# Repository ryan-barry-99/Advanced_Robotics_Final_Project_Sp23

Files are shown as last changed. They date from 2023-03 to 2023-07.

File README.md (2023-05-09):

# Balloon Trajectory Matching Omnidirectional Robot using YOLOv8

This project is designed to track a balloon using a custom YOLO model and a 3-wheeled omnidirectional drive robot, which can move in any direction without having to turn. The goal is to punch the balloon back into the air using the robot.

# Dataset and Model

The YOLOv8 model was trained on the V2 Balloon Detection dataset (https://www.kaggle.com/datasets/vbookshelf/v2-balloon-detection-dataset), resulting in efficient real-time detections at high accuracies. The model was trained using PyTorch, and the best weights were saved to the included yolov8_weights.pt file.

# Hardware Compatibility

For compatibility with DepthAI and OpenCV AI Kit hardware, the model must be saved in the Luxonis MyriadX Blob format. To achieve this, the weights were converted to the OpenVINO format using http://tools.luxonis.com/, and then the OpenVINO files were converted to the blob format using http://blobconverter.luxonis.com/.

# Code

The code for the ROS architecture that supports this robot is located in the Deployment folder. Files contained inside are as follows:
- QuadEncoder.py: Defines a class for extracting position and velocity data from quadrature encoders
- balloon_velocity.py: Deploys custom YOLOv8 model for detection and tracking, and publishes the velocity of a detected balloon
- forward_kinematics.py: Defines a class to compute the forward kinematics of an N-wheeled omnidirectional robot
- inverse_kinematics.py: Defines a class to compute the inverse kinematics of an N-wheeled omnidirectional robot
- motor.py: Defines a class for controlling a DC motor via software PWM signal
- pid_controller.py: Defines a PIDController class for use in updating wheel velocities
- pinout.py: Defines a dictionary containing the pinout for the robot. Updating pins here reflects the change globally
- robot_constants.py: Defines a dictionary containing the constants of an individual mobile robot. Updating the constants here reflects the change globally
- servo.py: Defines a class that enables PWM control for a servo
- update_target_velocity.py: Updates and publishes the robot's target velocity based on its current velocity and the balloon's velocity
- wheel_velocity_controller.py: Uses the PIDController class to match the robot's targeted and actual velocity

# Dependencies

For training YOLO:
- pandas
- numpy
- os
- ast
- sklearn
- shutil
- tqdm
- matplotlib
- torch
- IPython
- ultralytics
- clearml
- PyYAML

For Deployment:
- depthai
- time
- Jetson.GPIO
- math
- pathlib
- sys
- opencv-python
- numpy
- rospy

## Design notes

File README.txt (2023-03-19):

Balloon Puncher using YOLOv5 and Omnidirectional Robot

This project aims to track a balloon using YOLOv5 and punch it back into the air using a 3 wheeled omnidirectional drive robot. The robot moves in any direction without having to turn, which makes it perfect for this task.

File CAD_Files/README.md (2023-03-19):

# CAD Files for Tri-wheel Holonomic Robot
This repository contains the CAD (computer-aided design) files for a three wheeled omnidirectional drive robot. The CAD files are provided in SLDPRT and SLDASM and can be used for SOLIDWORKS 2021.

## Contents:
- 33_tooth_Gear.SLDPRT: 33 Tooth Gear to be 3D printed and screwed to side of wheel
- 3in_shaft.SLDPRT: Placeholder axle for chassis assembly. A carriage bolt was used on the physical prototype
- Bearing, Sealed, 608-2RS, 22X8X7.step.SLDPRT: 608-2RS bearing. 2 per wheel and 2 per wheel mount
- Din_Rail_8in.STEP: 8 inch aluminum din rail. Feel free to use another material of your choice but the brackets were designed for din rail
- Omni_Drive_Base.SLDASM: Full chassis assembly
- Omni_Roller.SLDPRT: 3D printable roller for Swedish wheel
- Omni_wheel_side.SLDPRT: Side panel of Swedish 90 wheel. Built in roller pins and press fit holes for bearings
- Omni_Wheel_Assembly.SLDASM: Full assembly of 3D printable Swedish 90 wheel
- Wheel_Mount.SLDPRT: 3D printable 120 deg bracket for wheel shafts. Press fit bearing holes
- clip.SLDPRT: Screw in clips to hold foam board on chassis
- spacer_025.SLDPRT: Allows wheel to freely rotate without interference from bolt head
- washer.SLDPRT: To be placed between wheel halfs and give rollers room for free rotation

## File Formats
The CAD files were created using SOLIDWORKS 2021 and are compatible with the 2021 version or later. If you need the files in a different format, you can use the software's export function to convert them.

## Usage
To open the CAD files, open SOLIDWORKS and select File > Open. Navigate to the location of the CAD files and select the one you want to open. You can then view and edit the part as needed.

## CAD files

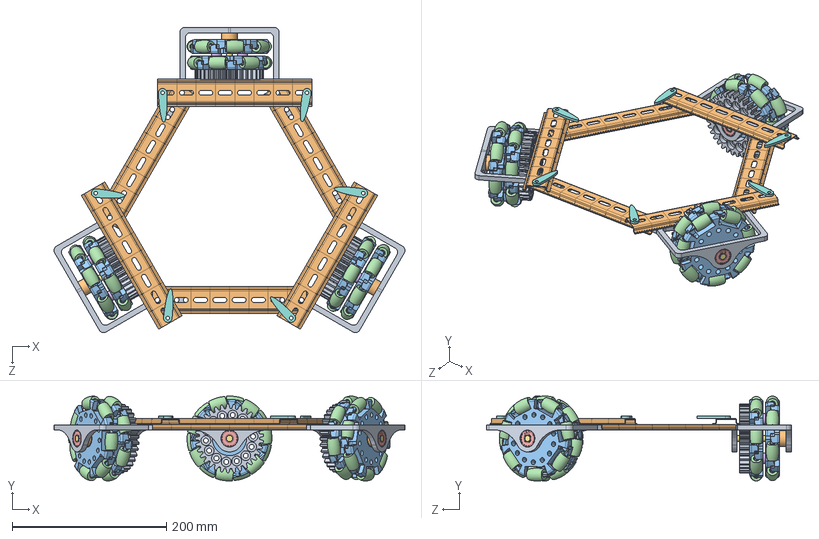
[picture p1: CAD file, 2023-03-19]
CAD_Files/Omni_Drive_Base.SLDASM
454.4 x 110.0 x 395.2 mm
Wheel_Mount x 3
din rail.STEP x 48
Omni_wheel_side x 12
Omni_Roller x 42
Bearing, Sealed, 608-2RS, 22X8X7.step x 12
washer x 6
3in_shaft x 3
clip x 6
33_tooth_Gear x 3
spacer_025 x 3

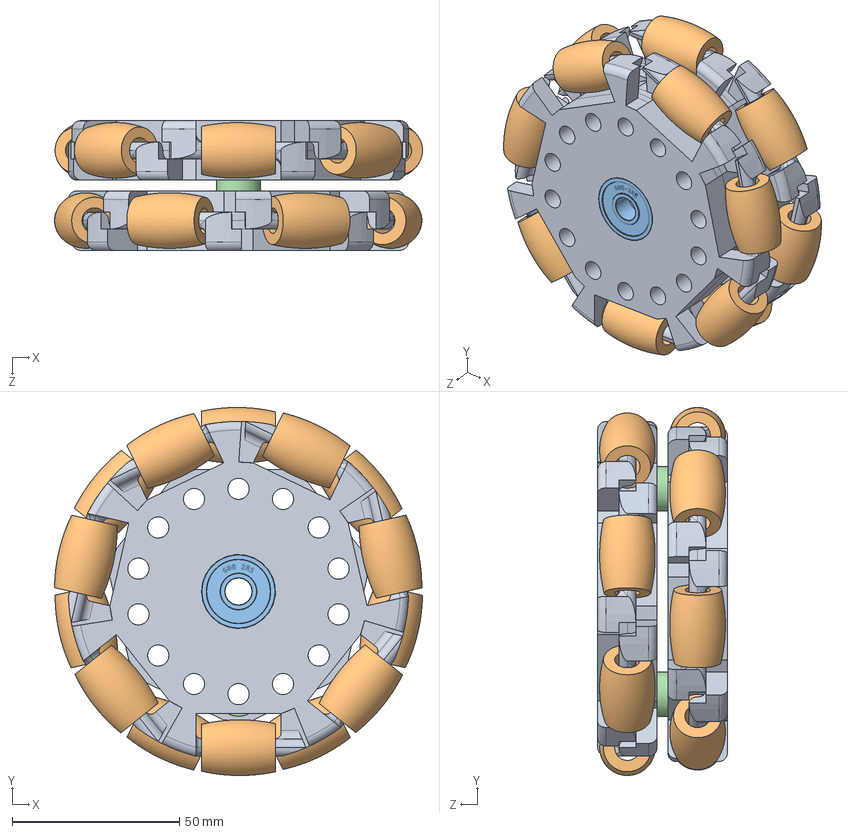
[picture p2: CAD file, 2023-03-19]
CAD_Files/Omni_Wheel_Assembly.SLDASM
109.9 x 109.9 x 38.7 mm
Omni_wheel_side x 4
Omni_Roller x 14
Bearing, Sealed, 608-2RS, 22X8X7.step x 2
washer x 2

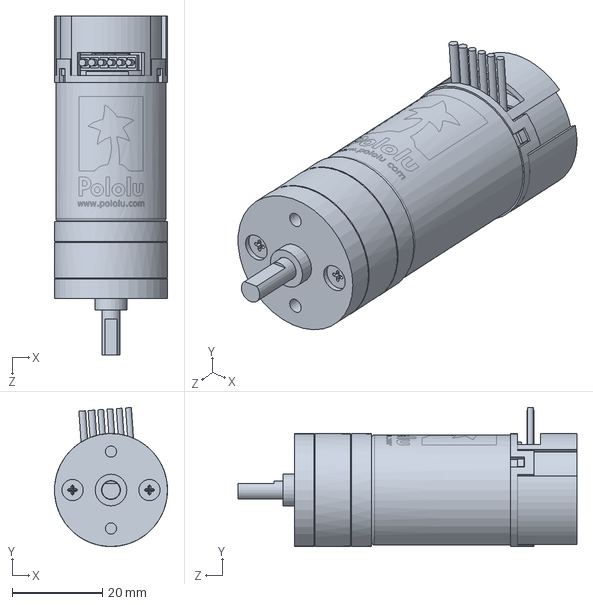
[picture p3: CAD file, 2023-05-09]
CAD_Files/25d-metal-gearmotor-4.4-9.7-encoder.SLDPRT
25.0 x 30.7 x 74.9 mm

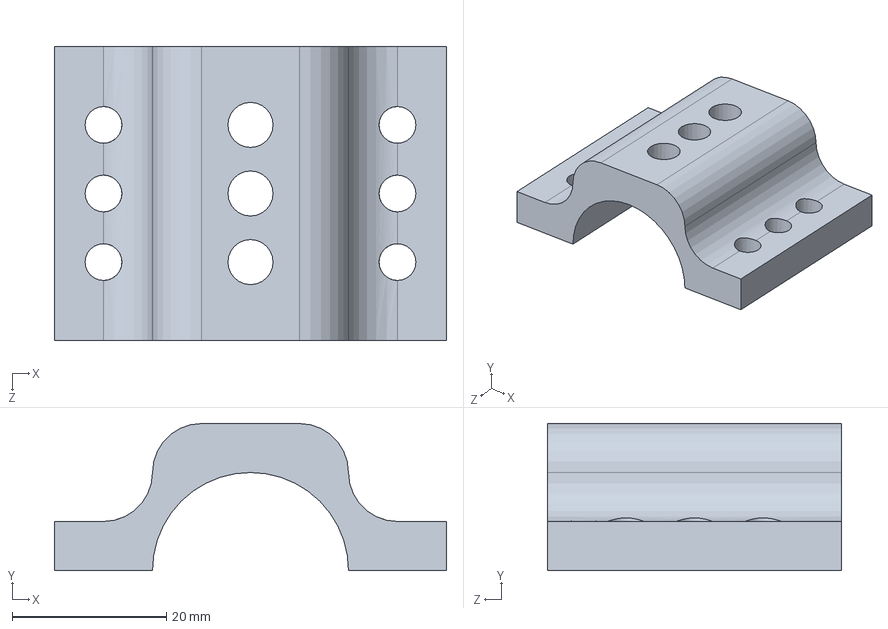
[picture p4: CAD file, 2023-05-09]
CAD_Files/Motor_Mount_Top.SLDPRT
50.8 x 19.1 x 38.1 mm

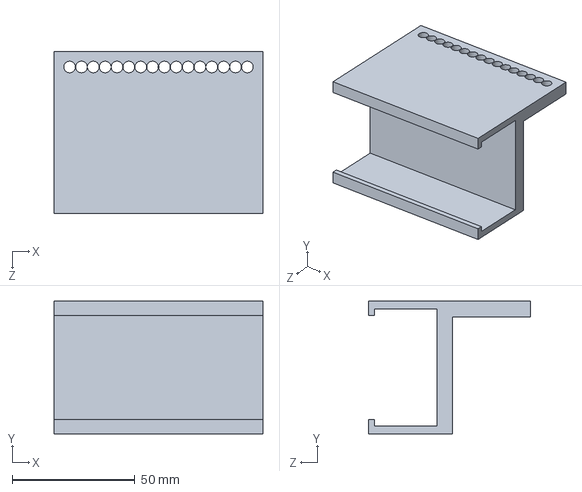
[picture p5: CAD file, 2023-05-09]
CAD_Files/Battery Holder.SLDPRT
85.1 x 54.0 x 66.0 mm

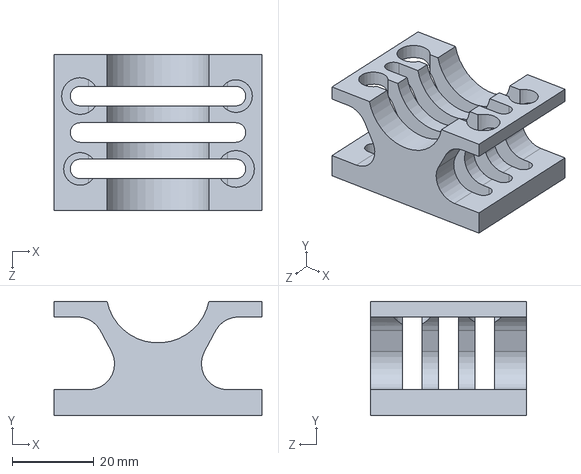
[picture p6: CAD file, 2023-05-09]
CAD_Files/Motor_Mount_Bottom.SLDPRT
50.8 x 27.9 x 38.1 mm

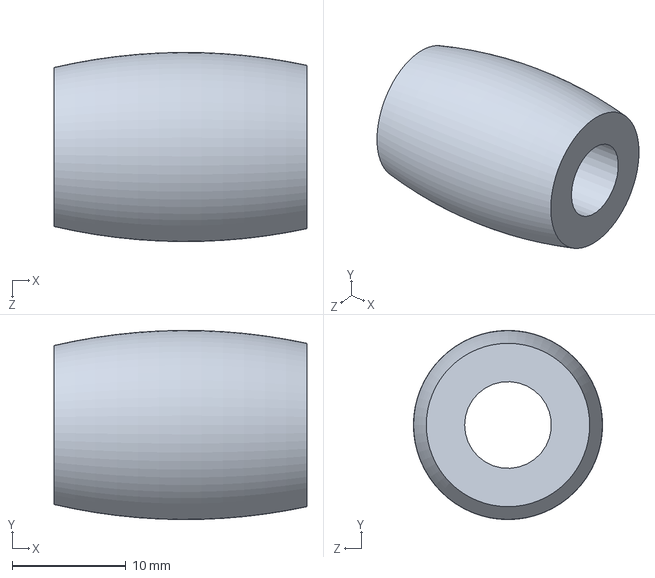
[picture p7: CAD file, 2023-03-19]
CAD_Files/Omni_Roller.SLDPRT
22.2 x 16.6 x 16.6 mm

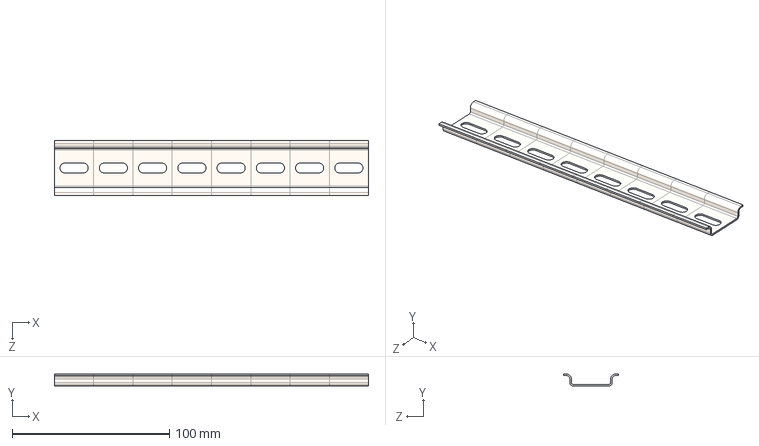
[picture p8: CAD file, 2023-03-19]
CAD_Files/Din_Rail_8in.STEP
200.0 x 7.50 x 35.0 mm
din rail x 8

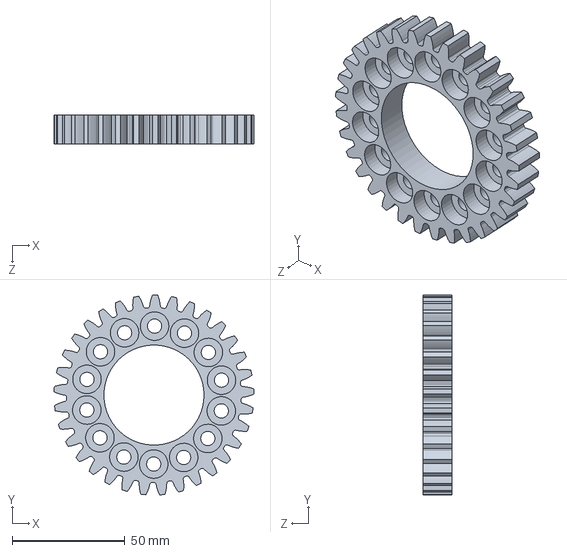
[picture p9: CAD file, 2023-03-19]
CAD_Files/33_tooth_Gear.SLDPRT
88.9 x 88.8 x 12.7 mm

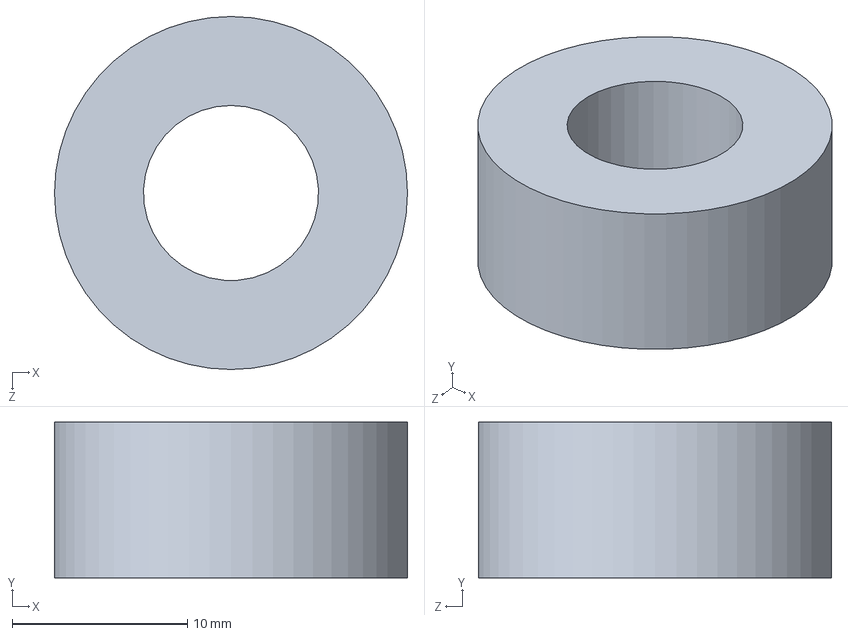
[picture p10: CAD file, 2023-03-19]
CAD_Files/spacer_025.SLDPRT
20.2 x 8.89 x 20.2 mm

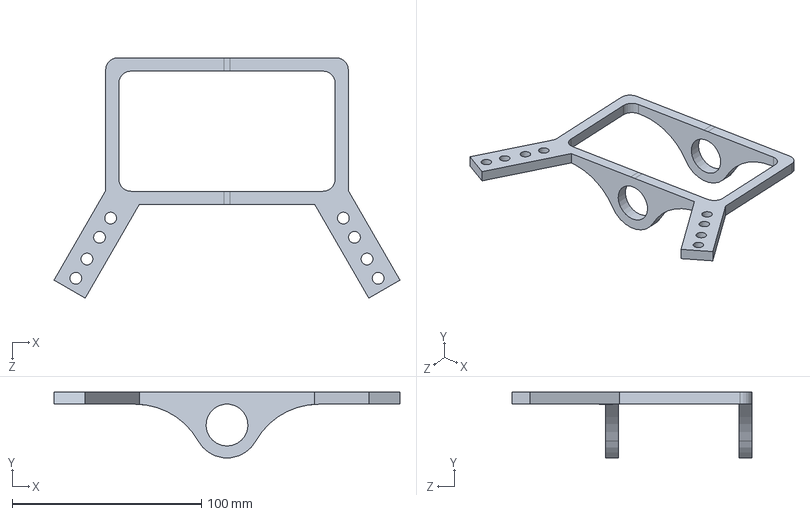
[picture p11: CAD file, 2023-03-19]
CAD_Files/Wheel_Mount.SLDPRT
182.9 x 34.6 x 127.0 mm

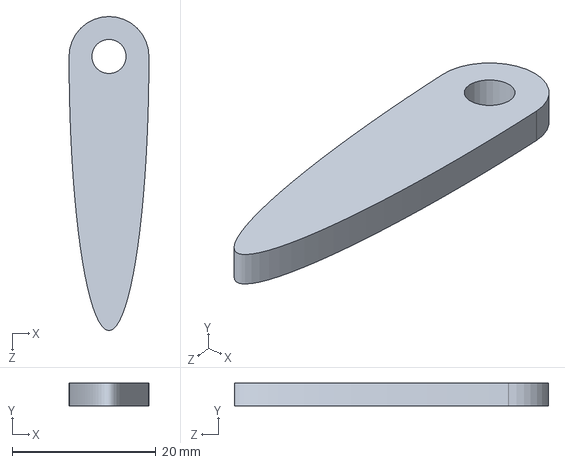
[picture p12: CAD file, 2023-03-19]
CAD_Files/clip.SLDPRT
11.1 x 3.17 x 43.7 mm

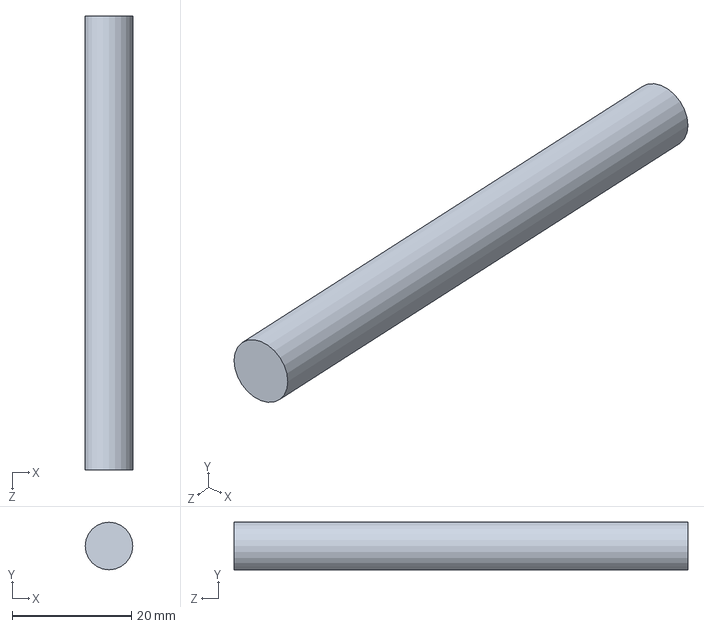
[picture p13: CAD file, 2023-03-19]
CAD_Files/3in_shaft.SLDPRT
8.00 x 8.00 x 76.2 mm

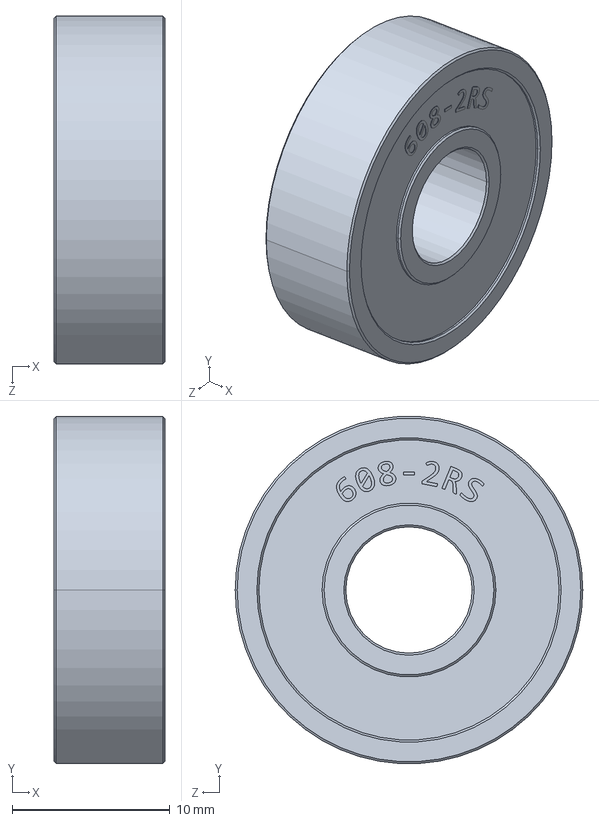
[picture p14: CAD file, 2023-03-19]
CAD_Files/Bearing, Sealed, 608-2RS, 22X8X7.step.SLDPRT
7.00 x 22.0 x 22.0 mm

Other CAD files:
CAD_Files/Omni_wheel_side.SLDPRT
CAD_Files/washer.SLDPRT

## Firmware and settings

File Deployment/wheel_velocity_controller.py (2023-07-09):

#!/usr/bin/env python

'''
This module provides the `Wheel` class which uses a `PIDController` object to update the direction and speed of each wheel on an omnidirectional robot.
The class subscribes to two ROS topics for the targeted and current velocities of each wheel and uses the `Motor` class to control the direction and speed of each wheel.

Default values for the `Wheel` class are defined in the robot_constants module.

The module initializes a ROS node and creates a list of `Wheel` objects for each wheel on the robot.
The main loop of the script runs until the ROS node is shut down and calls the `update` method of each `Wheel` object to update the direction and speed of each wheel based on the difference between its targeted and current velocities.

Author: Ryan Barry
Date created: April 28, 2023
'''

import rospy
import time
from std_msgs.msg import Float64
import numpy as np
from pinout import pinout
from robot_constants import constants
from pid_controller import PIDController
from motor import Motor

wheel_names = constants['wheel_names']
num_wheels = len(wheel_names)
kp = constants['kp']
ki = constants['ki']
kd = constants['kd']

class Wheel:
    def __init__(self, name, kp, ki, kd, wheel_number):
        self.pid = PIDController(kp, ki, kd)
        self.targeted_velocity = 0
        self.current_velocity = 0
        self.pwm = 0
        self.n = wheel_number
        self.motor = Motor(in1_pin=pinout[f'motor_{self.n+1}_dir_a'], in2_pin=pinout[f'motor_{self.n+1}_dir_b'], pwm_pin=pinout[f'motor_{self.n+1}_pwm'])

        rospy.Subscriber('velocity/wheel_velocities/'+name+'_target_vel', Float64, self.targeted_velocity_callback)
        rospy.Subscriber('velocity/wheel_velocities/'+name+'_vel', Float64, self.current_velocity_callback)


    def targeted_velocity_callback(self, target_vel):
        self.targeted_velocity = target_vel.data


    def current_velocity_callback(self, current_vel):
        self.current_velocity = current_vel.data


    def update(self):
        self.pwm += self.pid.update(self.targeted_velocity, self.current_velocity)
        if self.pwm >= 0:
            self.motor.set_direction('forward')
            self.motor.set_speed(min(self.pwm, 100))
        else:
            self.motor.set_direction('backward')
            self.motor.set_speed(min(-self.pwm, 100))

        self.motor.update_pwm()



if __name__ == '__main__':
    rospy.init_node("wheel_velocity_controller")
    wheels = []

    for i in range(num_wheels):
        wheels.append(Wheel(name=wheel_names[i], kp=kp[i], ki=ki[i], kd=kd[i], wheel_number=i+1))
 
    while not rospy.is_shutdown():
        for wheel in wheels:
            wheel.update()
        time.sleep(0.01)

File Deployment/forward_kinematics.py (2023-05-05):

#!/usr/bin/env python

'''
This module provides the `OmnidirectionalKinematics` class which calculates the linear and angular velocities of a three-wheeled omnidirectional robot.
The class uses the `QuadEncoder` class to obtain and publish the instantaneous velocity of the wheels.

Default values for the `OmnidirectionalForwardKinematics` class are defined in the robot_constants module

The module initializes a ROS node and creates publishers for the wheel and overall robot velocities.
The `run()` method of the `OmnidirectionalKinematics` class runs in a loop and uses the `QuadEncoder` class to obtain the instantaneous velocity 
of the wheels every 0.01 seconds, publishes them to ROS topics, and calculates the linear and angular velocities of the robot using the `calculate_robot_velocity()` method.

Author: Ryan Barry
Date created: April 22, 2023
'''


import rospy
import time
from pinout import pinout
from robot_constants import constants
from QuadEncoder import QuadEncoder
from std_msgs.msg import Float64
from geometry_msgs.msg import Twist
import numpy as np
from math import cos, sin, pi


# Default values for the class attributes
GEAR_RATIO = constants['gear_ratio']  # 4.4:1 Gear ratio motor with 11 tooth drive gear and 33 tooth driven gear
ENC_CPR = constants['enc_cpr']  # 48 CPR encoders
WHEEL_RADIUS = constants['wheel_radius']  # 2 inch radius wheels converted to meters
L = constants['base_width']  # Length from center of the robot to the center of the wheels converted to meters
WHEEL_NAMES = constants['wheel_names']
BETA = constants['beta']


class OmnidirectionalForwardKinematics :
    def __init__(self, BETA=BETA, WHEEL_NAMES=WHEEL_NAMES, GEAR_RATIO=GEAR_RATIO, ENC_CPR=ENC_CPR, WHEEL_RADIUS=WHEEL_RADIUS, L=L):
        """
        Initializes the `OmnidirectionalKinematics` instance.
        :param wheel_names: The names of wheels in the robot.
        :param gear_ratio: The gear ratio of the motor.
        :param enc_cpr: The encoder count per revolution.
        :param wheel_radius: The radius of the wheel in meters.
        :param L: The distance from the center of the robot to the center of the wheels in meters.
        """
        # Initialize ROS node
        rospy.init_node('forward_kinematics_node')

        # Define variables
        self.beta = BETA
        self.gear_ratio = GEAR_RATIO
        self.enc_cpr = ENC_CPR
        self.wheel_radius = WHEEL_RADIUS
        self.L = L
        self.wheel_names = WHEEL_NAMES
        self.num_wheels = len(self.wheel_names)
        self.alpha = [pi/self.num_wheels + 2*i*pi/self.num_wheels for i in range(self.num_wheels)]
        self.r_theta = np.eye(self.num_wheels)
        self.J1_list = []
        self.C1_list = []
        self.J2 = np.eye(self.num_wheels) * self.wheel_radius
        for i, _ in enumerate(self.wheel_names):
            self.J1_list.append(np.array([sin(self.alpha[i] + self.beta[i]), -cos(self.alpha[i] + self.beta[i]), -self.L*cos(self.beta[i])]))
            self.C1_list.append(np.array([cos(self.alpha[i] + self.beta[i]), sin(self.alpha[i] + self.beta[i]), self.L*sin(self.beta[i])]))
        self.J1 = np.array(self.J1_list).T
        self.C1 = np.array(self.C1_list).T


        # Create publishers for the velocities
        self.wheel_vel_pubs = []
        for i in range(self.num_wheels):
            self.wheel_vel_pubs.append(rospy.Publisher('velocity/wheel_velocities/'+self.wheel_names[i]+'_vel', Float64, queue_size=10))
        self.robot_vel_pub = rospy.Publisher('velocity/robot_velocity/current_velocity', Twist, queue_size=10)

        self.enc = []
        # Create EncoderReader instance
        for i in range(self.num_wheels):
            self.enc.append(QuadEncoder(encoder_A_pin=pinout[f'encoder_{i+1}_a'], encoder_B_pin=pinout[f'encoder_{i+1}_b'], gear_ratio=self.gear_ratio, wheel_radius=self.wheel_radius, encoder_cpr=self.enc_cpr))

    # Calculates the current linear and angular velocities of the robot
    def calculate_robot_velocity(self, velocities):
        zeta_dot = np.linalg.inv(self.r_theta) @ self.J1 @ self.J2 @ np.array(velocities)
        robot_vel = Twist()
        robot_vel.linear.x = zeta_dot[0]
        robot_vel.linear.y = zeta_dot[1]
        robot_vel.angular.z = zeta_dot[2]
        return robot_vel    

    # Uses QuadEncoder class to obtain and publish the instantaneous velocity of the wheels
    def run(self):
        while not rospy.is_shutdown():
            # Measure velocity every 0.01 seconds
            vel = []
            for i, _ in enumerate(self.wheel_vel_pubs):
                vel.append(self.enc[i].get_instantaneous_velocity())
                self.wheel_vel_pubs[i].publish(vel[i])

            self.robot_vel_pub.publish(self.calculate_robot_velocity(vel))
            time.sleep(0.01)
            
            
            
        # Clean up GPIO pins
        [self.enc[i].cleanup() for i in range(len(self.enc))]


if __name__ == '__main__':
    try:
        forward_kinematic_model = OmnidirectionalForwardKinematics()
        forward_kinematic_model.run()
    except rospy.ROSInterruptException:
        forward_kinematic_model.enc1.cleanup()
        forward_kinematic_model.enc2.cleanup()
        forward_kinematic_model.enc3.cleanup()

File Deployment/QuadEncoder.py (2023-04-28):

'''
This module provides the QuadEncoder class for obtaining position and velocity from an incremental encoder.
It uses the Jetson.GPIO library to interface with the GPIO pins of a Jetson Nano.

To use this class, the user must provide the GPIO pin numbers of the encoder A and B channels, 
the gear ratio of the system, the wheel radius, and the encoder counts per revolution (CPR).

Author: Ryan Barry
Date created: April 22, 2023
'''

import time
import Jetson.GPIO as GPIO
from math import pi

# Quadrature Encoder class to obtain position and velocity from a quadrature encoder
class QuadEncoder:
    def __init__(self, encoder_A_pin, encoder_B_pin, gear_ratio, wheel_radius, encoder_cpr):
        self.encoder_A_pin = encoder_A_pin
        self.encoder_B_pin = encoder_B_pin
        self.gear_ratio = gear_ratio
        self.wheel_radius = wheel_radius
        self.encoder_cpr = encoder_cpr
        self.encoder_pos = 0
        self.last_pos = 0
        self.last_time = 0
        GPIO.setmode(GPIO.BOARD)
        GPIO.setup(encoder_A_pin, GPIO.IN)
        GPIO.setup(encoder_B_pin, GPIO.IN)
        GPIO.add_event_detect(encoder_A_pin, GPIO.BOTH, callback=self.encoder_callback)

    # Interrupt to update the encoder count
    def encoder_callback(self, channel):
        if GPIO.input(self.encoder_A_pin) == GPIO.input(self.encoder_B_pin):
            self.encoder_pos += 1
        else:
            self.encoder_pos -= 1

    # Calculates net distance traveled by the wheel between calls of this function
    def get_distance_since_last_call(self):
        current_pos = self.encoder_pos
        distance_per_count = 2 * pi * self.wheel_radius / (self.encoder_cpr * 4 * self.gear_ratio)
        distance_traveled = (current_pos - self.last_pos) * distance_per_count
        self.last_pos = current_pos
        return distance_traveled

    # Calculate average velocity of a wheel over time window size parameter, duration
    def get_wheel_velocity_duration(self, duration):
        start_pos = self.encoder_pos
        start_time = time.monotonic()
        time.sleep(duration)
        end_pos = self.encoder_pos
        end_time = time.monotonic()
        counts_per_second = (end_pos - start_pos) / (end_time - start_time)
        counts_per_revolution = self.encoder_cpr * 4
        wheel_circumference = 2 * pi * self.wheel_radius
        wheel_velocity = counts_per_second * wheel_circumference * self.gear_ratio / counts_per_revolution
        return wheel_velocity

    # Calculate the instantaneous velocity of a wheel between the last two encoder position updates
    def get_instantaneous_velocity(self):
        current_pos = self.encoder_pos
        current_time = time.monotonic()
        counts_per_second = (current_pos - self.last_pos) / (current_time - self.last_time)
        counts_per_revolution = self.encoder_cpr * 4
        wheel_circumference = 2 * pi * self.wheel_radius
        wheel_velocity = counts_per_second * wheel_circumference * self.gear_ratio / counts_per_revolution
        self.last_pos = current_pos
        self.last_time = current_time
        return wheel_velocity

    # Function to reset GPIO pin modes
    def cleanup(self):
        GPIO.cleanup(self.encoder_A_pin)
        GPIO.cleanup(self.encoder_B_pin)

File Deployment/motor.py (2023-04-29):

'''
This module provides the Motor class for controlling the speed and direction of a DC motor using PWM signals.
It uses the Jetson.GPIO library to interface with the GPIO pins of a Jetson Nano.

To use this class, the user must specify the GPIO pin numbers for the motor's IN1, IN2, and PWM pins.

Author: Ryan Barry
Date created: April 27, 2023
'''

import Jetson.GPIO as GPIO
from robot_constants import constants
import time

class Motor:
    def __init__(self, in1_pin, in2_pin, pwm_pin):
        self.in1_pin = in1_pin
        self.in2_pin = in2_pin
        self.pwm_pin = pwm_pin
        self.duty_cycle = 0
        self.frequency = constants['motor_frequency']
        self.pwm_running = False
        self.next_toggle_time = 0
        GPIO.setmode(GPIO.BOARD)
        GPIO.setup(self.in1_pin, GPIO.OUT)
        GPIO.setup(self.in2_pin, GPIO.OUT)
        GPIO.setup(self.pwm_pin, GPIO.OUT)

    def set_direction(self, direction):
        if direction == 'forward':
            GPIO.output(self.in1_pin, GPIO.HIGH)
            GPIO.output(self.in2_pin, GPIO.LOW)
        elif direction == 'backward':
            GPIO.output(self.in1_pin, GPIO.LOW)
            GPIO.output(self.in2_pin, GPIO.HIGH)
        elif direction == 'active_stop':
            GPIO.output(self.in1_pin, GPIO.HIGH)
            GPIO.output(self.in2_pin, GPIO.HIGH)
        elif direction == 'passive_stop':
            GPIO.output(self.in1_pin, GPIO.LOW)
            GPIO.output(self.in2_pin, GPIO.LOW)

    def set_speed(self, duty_cycle):
        self.duty_cycle = duty_cycle

    def update_pwm(self):
        current_time = time.monotonic()
        if current_time >= self.next_toggle_time:
            if GPIO.input(self.pwm_pin) == GPIO.HIGH:
                off_time = 1 / self.frequency * (1 - (self.duty_cycle / 100))
                self.next_toggle_time = current_time + off_time
                GPIO.output(self.pwm_pin, GPIO.LOW)
            else:
                on_time = 1 / self.frequency * (self.duty_cycle / 100)
                self.next_toggle_time = current_time + on_time
                GPIO.output(self.pwm_pin, GPIO.HIGH)
